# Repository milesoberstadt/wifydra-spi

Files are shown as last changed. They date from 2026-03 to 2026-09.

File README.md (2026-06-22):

# Wifydra-SPI 

A distributed WiFi beacon sniffing system using an ESP32-S3-DevKitC-1 as a central Controller and multiple ESP32-C5 nodes as Workers, with one C5 node per WiFi channel. The device uses SPI to enable synchronization of time, GPS coordinates, and aggregate WiFi discovery data.

Shout out to [lozaning's Wifydra](https://github.com/lozaning/The_Wifydra) for the inspiration!

## Features
- **Passive:** Workers operate in promiscuous mode on a fixed channel, ensuring no missed beacons due to the channel hopping in an active scan.
- **Simplified flashing:** I used SPI's CS pin assignment as unique identifiers, channels are assigned at runtime by the controller. 
- **Wigle Compatibility:** Data is stored in Wigle-compatible structures with first-seen timestamps and RSSI tracking.

## Parts List
- **Controller:** ESP32-S3-DevKitC-1, chosen for its high GPIO count and native USB/SPI support
- **Workers:** 16x Seeed Studio ESP32-C5 (or other compatible ESP32 modules)
- **GPS:** NEO-6M u-blox module, any 5v module should work
- **SD Card:** I used a Pzsmocn microSD module, any 3.3v SPI module should work
- **Buck Converter:** Bucking from 5v to 3.3v for the SD card
- **Resistors:** Every SPI connected device (including the microSD) needs a 10k ohm resistor tying the device's 3.3v line to CS

## Hardware Wiring

Current prototype diagram: https://app.cirkitdesigner.com/project/823f8a95-0d39-48f3-8a6c-8a6a2daa64cd

### SPI Bus Connections
| Signal | ESP32-S3-DevKitC-1 (Controller) | ESP32-S3 (Worker x) | SD Card (SPI Mode) |
| :--- | :--- | :--- | :--- |
| **SCLK** | GPIO 12 | GPIO 7 | SCLK |
| **MISO** | GPIO 13 | GPIO 8 | MISO |
| **MOSI** | GPIO 11 | GPIO 9 | MOSI |
| **GND** | GND | GND | GND |

### Chip Select (CS) Connections
| Target | ESP32-S3-DevKitC-1 (Controller CS Pin) | ESP32-S3 (Worker CS Pin) |
| :--- | :--- | :--- |
| **Worker 1** | GPIO 4 | GPIO 2 |
| **Worker 2** | GPIO 5 | GPIO 2 |
| **Worker 3** | GPIO 6 | GPIO 2 |
| **Worker 4** | GPIO 7 | GPIO 2 |
| **Worker 5** | GPIO 15 | GPIO 2 |
| **Worker 6** | GPIO 18 | GPIO 2 |
| **Worker 7** | GPIO 8 | GPIO 2 |
| **Worker 8** | GPIO 9 | GPIO 2 |
| **Worker 9** | GPIO 2 | GPIO 2 |
| **Worker 10** | GPIO 42 | GPIO 2 |
| **Worker 11** | GPIO 41 | GPIO 2 |
| **Worker 12** | GPIO 40 | GPIO 2 |
| **Worker 13** | GPIO 39 | GPIO 2 |
| **Worker 14** | GPIO 21 | GPIO 2 |
| **Worker 15** | GPIO 10 | GPIO 2 |
| **Worker 16** | GPIO 14 | GPIO 2 |
| **SD Card** | GPIO 1 | N/A |

### GPS Connections (Controller Only)
| Peripheral | Signal | ESP32-S3-DevKitC-1 (Controller) | Notes |
| :--- | :--- | :--- | :--- |
| **GPS (UART2)** | TX | GPIO 17 | Connect to GPS RX |
| **GPS (UART2)** | RX | GPIO 16 | Connect to GPS TX |

## Requirements
- ESP-IDF 5.x environment sourced: `. $IDF_PATH/export.sh`

## Flashing 
- **Controller:**
  ```bash
  cd controller
  idf.py build
  idf.py flash
  ```
- **Worker:**
  ```bash
  cd worker
  idf.py build
  idf.py flash
  ```

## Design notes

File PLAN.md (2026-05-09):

# SPI Communication Project Plan: ESP32 Controller to 3x ESP32-S3 Workers

### Scaling to 15 Workers (6GHz PSC channels) [TODO]
- **CS Multiplexing:** 
    - Implement a **4-to-16 Decoder** (e.g., 74HC154) or **GPIO Expander** (e.g., MCP23017) to control 15 CS lines using only 4 controller pins.
    - Software: Update SPI polling loop to set the address on the decoder pins before each transaction.
- **Bus Integrity:** 
    - Evaluate need for SPI bus buffers/drivers (e.g., 74HC244) to handle increased capacitance of 15 slaves.
    - Implement per-worker channel locking (Worker 1 -> Ch 1, Worker 2 -> Ch 2, etc.).
- **Power Management:** Investigate current draw for 15 workers + GPS + SD card

---

## Upcoming Tasks
0. [ ] Update to ESP-IDF 6
1. [ ] Prototype Phase 9 CS multiplexing hardware.
2. [ ] Evaluate SPI bus buffers for 11-worker scale.

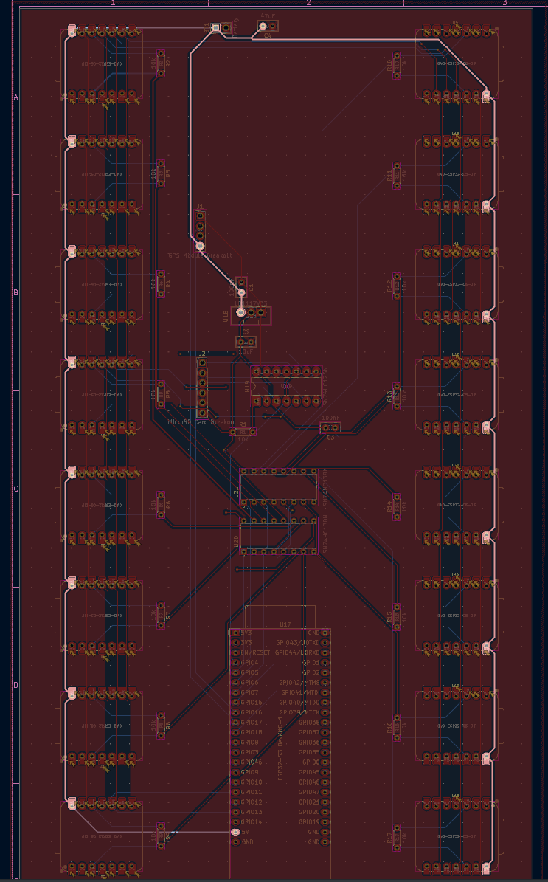
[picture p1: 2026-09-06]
img/power_net.png

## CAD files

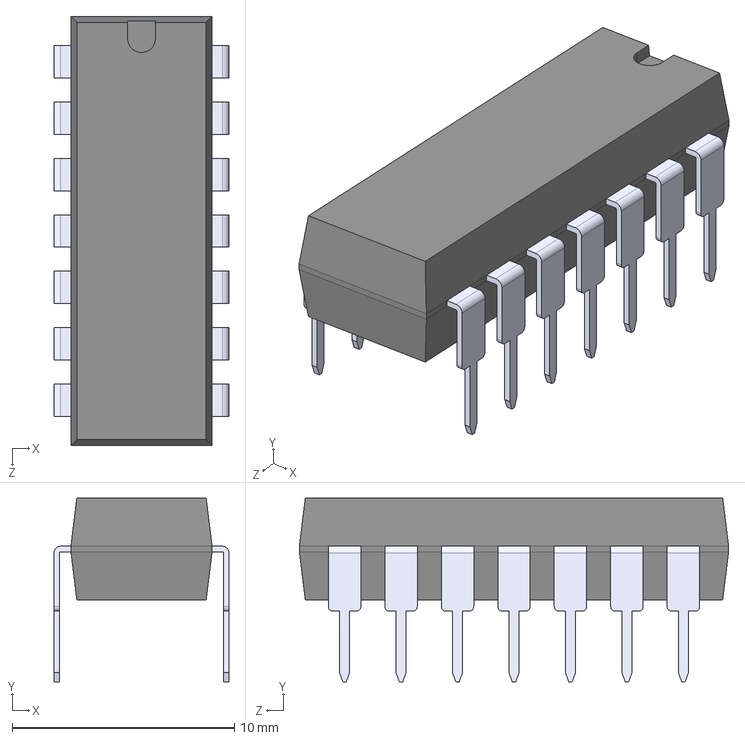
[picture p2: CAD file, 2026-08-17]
pcb/SN74HC125N/SN74HC125N.step
7.87 x 8.26 x 19.3 mm

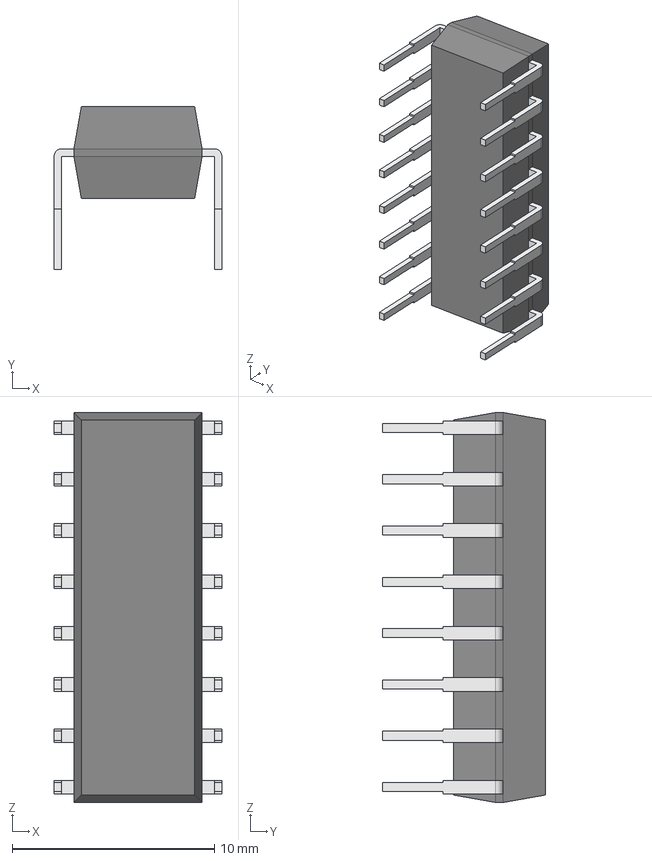
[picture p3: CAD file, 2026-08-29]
pcb/SN74HC138N/SN74HC138N.step
8.31 x 8.08 x 19.3 mm
Body001 (Mirror #1) x 9

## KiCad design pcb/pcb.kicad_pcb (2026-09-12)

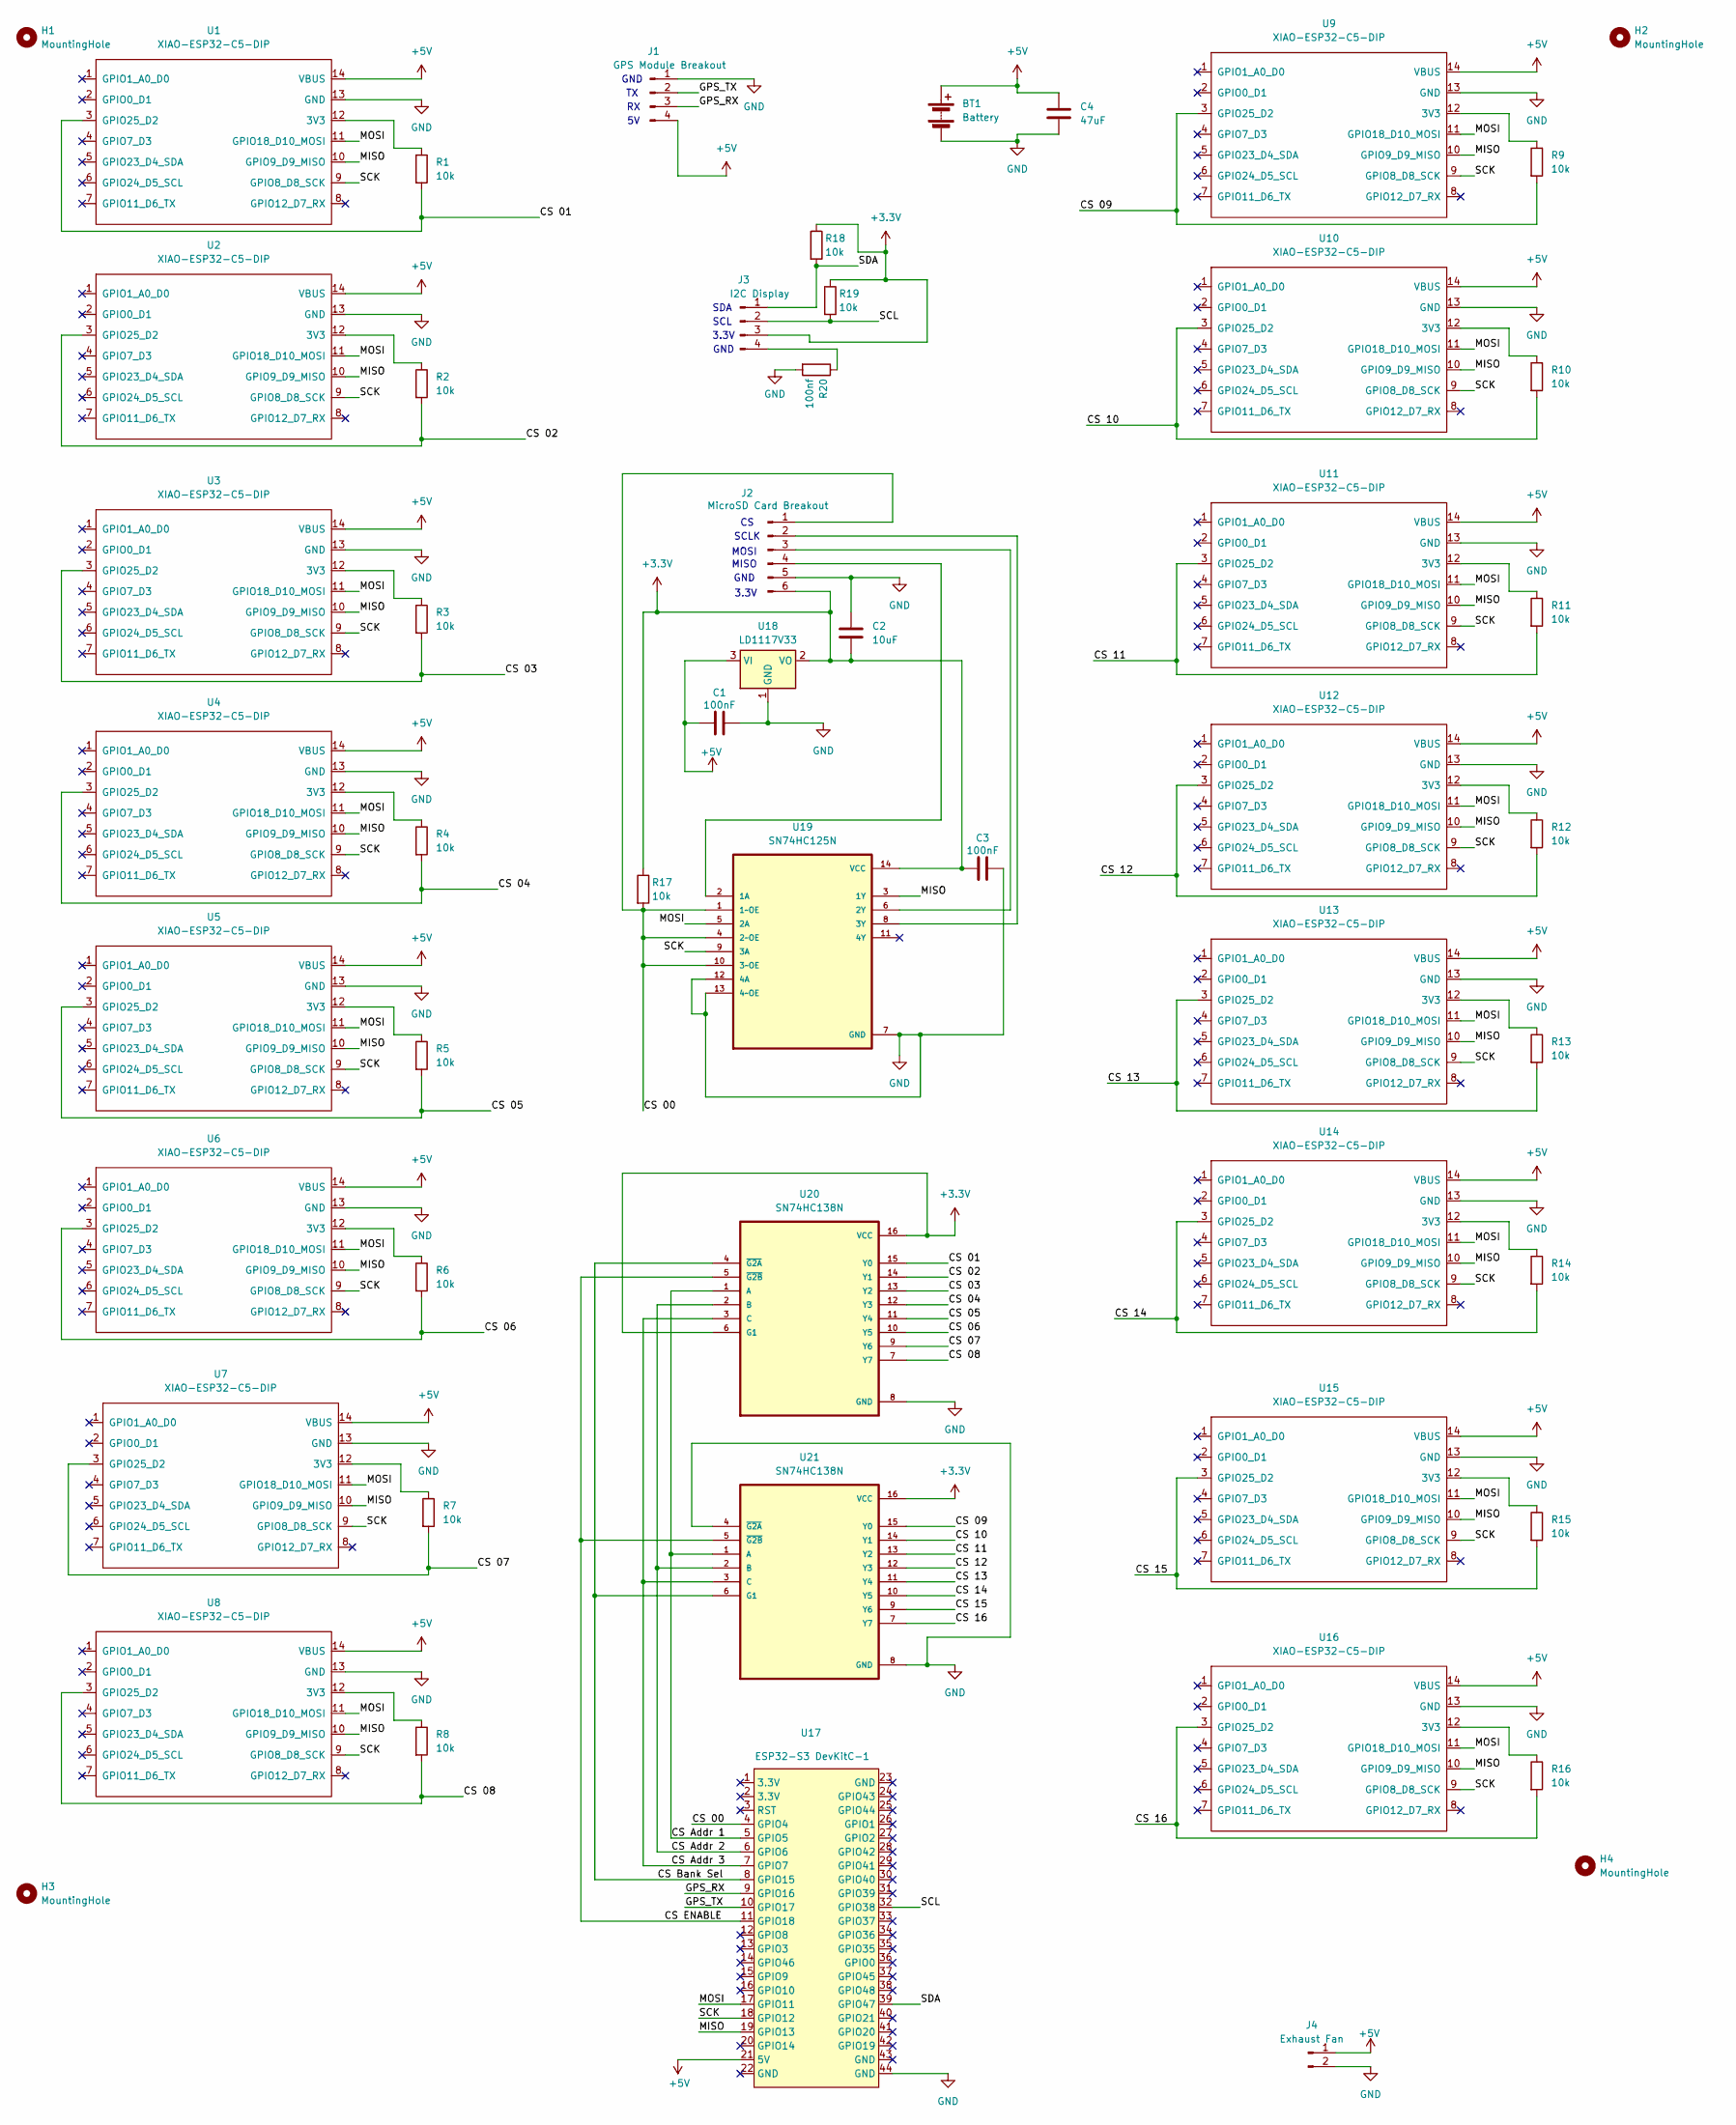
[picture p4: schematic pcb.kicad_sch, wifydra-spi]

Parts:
BT1: Battery; PinHeader_1x02_P2.54mm_Vertical
C1, C3: 100nF; C_Disc_D5.0mm_W2.5mm_P2.50mm
C2: 10uF; C_Disc_D5.0mm_W2.5mm_P2.50mm
C4: 47uF; C_Disc_D5.0mm_W2.5mm_P2.50mm
H1, H2, H3, H4: MountingHole; MountingHole_3.2mm_M3
J1: GPS Module Breakout; PinHeader_1x04_P2.54mm_Vertical
J2: MicroSD Card Breakout; PinHeader_1x06_P2.54mm_Vertical
J3: I2C Display; PinHeader_1x04_P2.54mm_Vertical
J4: Exhaust Fan; PinHeader_1x02_P2.54mm_Vertical
R1, R2, R3, R4, R5, R6, R7, R8, R9, R10, R11, R12, R13, R14, R15, R16, R17, R18, R19: 10k; R_Axial_DIN0204_L3.6mm_D1.6mm_P5.08mm_Horizontal
R20: 100nf; R_Axial_DIN0204_L3.6mm_D1.6mm_P5.08mm_Horizontal
U1, U2, U3, U4, U5, U6, U7, U8, U9, U10, U11, U12, U13, U14, U15, U16: XIAO-ESP32-C5-DIP
U17: ESP32-S3 DevKitC-1; ESP32-S3-DevKitC
U18: LD1117V33; TO-220-3_Vertical
U19: SN74HC125N; DIP-14_W7.62mm_LongPads
U20, U21: SN74HC138N; DIP794W45P254L1969H508Q16; DigiKey_Part_Number 296-1575-5-ND

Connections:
+3.3V: C2.1, C3.2, J2.6, J3.3, R17.1, R18.1, R19.1, U18.2 (VO), U19.14 (VCC), U20.6 (G1), U20.16 (VCC), U21.16 (VCC)
+5V: BT1.1 (+), C1.2, C4.2, J1.4, J4.1, U1.14 (VBUS), U2.14 (VBUS), U3.14 (VBUS), U4.14 (VBUS), U5.14 (VBUS), U6.14 (VBUS), U7.14 (VBUS), U8.14 (VBUS), U9.14 (VBUS), U10.14 (VBUS), U11.14 (VBUS), U12.14 (VBUS), U13.14 (VBUS), U14.14 (VBUS), U15.14 (VBUS), U16.14 (VBUS), U17.21 (5V), U18.3 (VI)
/CS 00: J2.1, R17.2, U17.4 (GPIO4), U19.1 (1~OE), U19.4 (2~OE), U19.10 (3~OE)
/CS 01: R1.2, U1.3 (GPIO25_D2), U20.15 (Y0)
/CS 02: R2.2, U2.3 (GPIO25_D2), U20.14 (Y1)
/CS 03: R3.2, U3.3 (GPIO25_D2), U20.13 (Y2)
/CS 04: R4.2, U4.3 (GPIO25_D2), U20.12 (Y3)
/CS 05: R5.2, U5.3 (GPIO25_D2), U20.11 (Y4)
/CS 06: R6.2, U6.3 (GPIO25_D2), U20.10 (Y5)
/CS 07: R7.2, U7.3 (GPIO25_D2), U20.9 (Y6)
/CS 08: R8.2, U8.3 (GPIO25_D2), U20.7 (Y7)
/CS 09: R9.2, U9.3 (GPIO25_D2), U21.15 (Y0)
/CS 10: R10.2, U10.3 (GPIO25_D2), U21.14 (Y1)
/CS 11: R11.2, U11.3 (GPIO25_D2), U21.13 (Y2)
/CS 12: R12.2, U12.3 (GPIO25_D2), U21.12 (Y3)
/CS 13: R13.2, U13.3 (GPIO25_D2), U21.11 (Y4)
/CS 14: R14.2, U14.3 (GPIO25_D2), U21.10 (Y5)
/CS 15: R15.2, U15.3 (GPIO25_D2), U21.9 (Y6)
/CS 16: R16.2, U16.3 (GPIO25_D2), U21.7 (Y7)
/CS Addr 1: U17.5 (GPIO5), U20.1 (A), U21.1 (A)
/CS Addr 2: U17.6 (GPIO6), U20.2 (B), U21.2 (B)
/CS Addr 3: U17.7 (GPIO7), U20.3 (C), U21.3 (C)
/CS Bank Sel: U17.8 (GPIO15), U20.4 (~G2A), U21.6 (G1)
/CS ENABLE: U17.11 (GPIO18), U20.5 (~G2B), U21.5 (~G2B)
/GPS_RX: J1.3, U17.9 (GPIO16)
/GPS_TX: J1.2, U17.10 (GPIO17)
/MISO: U1.10 (GPIO9_D9_MISO), U2.10 (GPIO9_D9_MISO), U3.10 (GPIO9_D9_MISO), U4.10 (GPIO9_D9_MISO), U5.10 (GPIO9_D9_MISO), U6.10 (GPIO9_D9_MISO), U7.10 (GPIO9_D9_MISO), U8.10 (GPIO9_D9_MISO), U9.10 (GPIO9_D9_MISO), U10.10 (GPIO9_D9_MISO), U11.10 (GPIO9_D9_MISO), U12.10 (GPIO9_D9_MISO), U13.10 (GPIO9_D9_MISO), U14.10 (GPIO9_D9_MISO), U15.10 (GPIO9_D9_MISO), U16.10 (GPIO9_D9_MISO), U17.19 (GPIO13), U19.3 (1Y)
/MOSI: U1.11 (GPIO18_D10_MOSI), U2.11 (GPIO18_D10_MOSI), U3.11 (GPIO18_D10_MOSI), U4.11 (GPIO18_D10_MOSI), U5.11 (GPIO18_D10_MOSI), U6.11 (GPIO18_D10_MOSI), U7.11 (GPIO18_D10_MOSI), U8.11 (GPIO18_D10_MOSI), U9.11 (GPIO18_D10_MOSI), U10.11 (GPIO18_D10_MOSI), U11.11 (GPIO18_D10_MOSI), U12.11 (GPIO18_D10_MOSI), U13.11 (GPIO18_D10_MOSI), U14.11 (GPIO18_D10_MOSI), U15.11 (GPIO18_D10_MOSI), U16.11 (GPIO18_D10_MOSI), U17.17 (GPIO11), U19.5 (2A)
/SCK: U1.9 (GPIO8_D8_SCK), U2.9 (GPIO8_D8_SCK), U3.9 (GPIO8_D8_SCK), U4.9 (GPIO8_D8_SCK), U5.9 (GPIO8_D8_SCK), U6.9 (GPIO8_D8_SCK), U7.9 (GPIO8_D8_SCK), U8.9 (GPIO8_D8_SCK), U9.9 (GPIO8_D8_SCK), U10.9 (GPIO8_D8_SCK), U11.9 (GPIO8_D8_SCK), U12.9 (GPIO8_D8_SCK), U13.9 (GPIO8_D8_SCK), U14.9 (GPIO8_D8_SCK), U15.9 (GPIO8_D8_SCK), U16.9 (GPIO8_D8_SCK), U17.18 (GPIO12), U19.9 (3A)
/SCL: J3.2, R19.2, U17.32 (GPIO38)
/SDA: J3.1, R18.2, U17.39 (GPIO47)
GND: BT1.2 (-), C1.1, C2.2, C3.1, C4.1, J1.1, J2.5, J4.2, R20.2, U1.13 (GND), U2.13 (GND), U3.13 (GND), U4.13 (GND), U5.13 (GND), U6.13 (GND), U7.13 (GND), U8.13 (GND), U9.13 (GND), U10.13 (GND), U11.13 (GND), U12.13 (GND), U13.13 (GND), U14.13 (GND), U15.13 (GND), U16.13 (GND), U17.44 (GND), U18.1 (GND), U19.7 (GND), U19.12 (4A), U19.13 (4~OE), U20.8 (GND), U21.4 (~G2A), U21.8 (GND)
unnamed: J2.2, U19.8 (3Y)
unnamed: J2.3, U19.6 (2Y)
unnamed: J2.4, U19.2 (1A)
unnamed: J3.4, R20.1
unnamed: R1.1, U1.12 (3V3)
unnamed: R2.1, U2.12 (3V3)
unnamed: R3.1, U3.12 (3V3)
unnamed: R4.1, U4.12 (3V3)
unnamed: R5.1, U5.12 (3V3)
unnamed: R6.1, U6.12 (3V3)
unnamed: R7.1, U7.12 (3V3)
unnamed: R8.1, U8.12 (3V3)
unnamed: R9.1, U9.12 (3V3)
unnamed: R10.1, U10.12 (3V3)
unnamed: R11.1, U11.12 (3V3)
unnamed: R12.1, U12.12 (3V3)
unnamed: R13.1, U13.12 (3V3)
unnamed: R14.1, U14.12 (3V3)
unnamed: R15.1, U15.12 (3V3)
unnamed: R16.1, U16.12 (3V3)

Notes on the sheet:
3.3V
SCL
GND
MISO
SDA
MOSI
SCLK

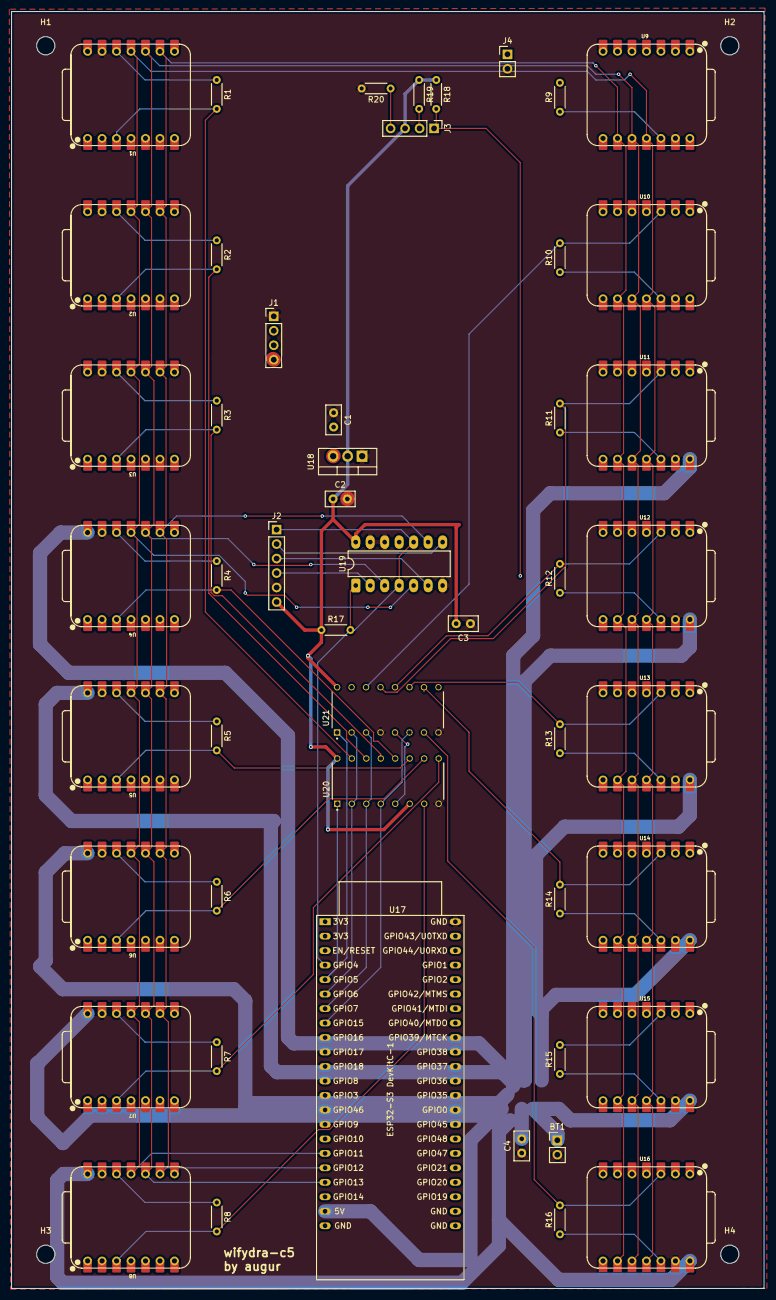
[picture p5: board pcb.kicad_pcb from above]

Board: 2 copper layers, 132.0 x 224.0 mm, 54 parts (0 on the bottom side), 52 nets.

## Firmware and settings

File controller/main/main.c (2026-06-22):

#include <stdio.h>
#include <string.h>
#include "freertos/FreeRTOS.h"
#include "freertos/task.h"
#include "driver/spi_master.h"
#include "driver/gpio.h"
#include "driver/uart.h"
#include "esp_log.h"
#include "esp_heap_caps.h"
#include "nvs_flash.h"
#include "nvs.h"
#include "esp_vfs_fat.h"
#include "driver/sdspi_host.h"
#include "driver/spi_common.h"
#include <errno.h>

static const char *TAG = "CONTROLLER";

// --- Configuration ---
#define CONFIG_WAIT_FOR_GPS_FIX true  // If true, controller won't poll workers until GPS has a fix
// ---------------------

#define GPIO_SCLK 12
#define GPIO_MISO 13
#define GPIO_MOSI 11
#define GPIO_LED  47
#define SD_CS_PIN 10
#define NUM_WORKERS 16

static const int cs_pins[NUM_WORKERS] = {
    4, 5, 6, 7, 15, 18, 8, 9, 2, 42, 41, 40, 39, 21, 10, 14
};

// GPS UART Config
#define GPS_UART_NUM UART_NUM_2
#define GPS_TX_PIN 17
#define GPS_RX_PIN 16
#define GPS_BUF_SIZE 1024

#define PAYLOAD_SIZE 5100
#define HANDSHAKE_CMD 0xAB
#define HANDSHAKE_ACK 0xBA

// NVS Keys
#define NVS_NAMESPACE "gps_data"
#define NVS_KEY_LAT "last_lat"
#define NVS_KEY_LON "last_lon"

spi_device_handle_t workers[NUM_WORKERS];

typedef struct __attribute__((packed)) {
    float latitude;
    float longitude;
} gps_coords_t;

static gps_coords_t current_gps = { .latitude = 0.0f, .longitude = 0.0f };
static uint32_t current_unix_time = 1740950400; // Default start time

uint16_t calculate_checksum(const uint8_t *data, size_t len) {
    uint32_t sum = 0;
    for (size_t i = 0; i < len; i++) sum += data[i];
    return (uint16_t)(sum & 0xFFFF);
}

typedef struct __attribute__((packed)) {
    uint8_t command;
    uint8_t wifi_channel;
    uint32_t unix_time;
    gps_coords_t gps;
    uint8_t padding[5100 - 14];
} controller_msg_t;

typedef struct __attribute__((packed)) {
    uint8_t status;
    uint8_t reserved;
    uint16_t checksum;
    uint8_t data[5100 - 4];
} worker_msg_t;

typedef struct __attribute__((packed)) {
    uint8_t bssid[6];
    char ssid[33];
    char capabilities[40];
    uint32_t first_seen;
    uint8_t channel;
    int8_t rssi;
    float lat;
    float lon;
    uint32_t hits;
    uint8_t sent;
} wigle_record_t;

static const uint8_t popular_channels[] = {1, 6, 11, 2, 7, 3, 8, 4, 9, 5, 10};
// 5 GHz non-DFS channels
// static const uint8_t popular_channels[] = {36, 40, 44, 48, 149, 153, 157, 161, 165};
// 6 GHz PSC channels
// static const uint8_t popular_channels[] = {5,21,37,53,69,85,101,117,133,149,165,181,197,213,229};
static uint8_t worker_current_channels[NUM_WORKERS]; 

// NMEA Parsing State
static bool gps_data_seen = false;
static bool gps_fix_acquired = false;
static bool sd_card_ready = false;

// SD Card Handle
sdmmc_card_t *card;
#define MOUNT_POINT "/sdcard"

void init_sd_card() {
    ESP_LOGI(TAG, "Initializing SD card (SPI)");

    esp_vfs_fat_mount_config_t mount_config = {
        .format_if_mount_failed = true,
        .max_files = 5,
        .allocation_unit_size = 16 * 1024
    };

    ESP_LOGI(TAG, "Using SPI peripheral");

    // Host configuration
    sdmmc_host_t host = SDSPI_HOST_DEFAULT();
    host.slot = HSPI_HOST; // Use the same host as workers
    host.max_freq_khz = 1000; // 1MHz stability limit

    // Device configuration
    sdspi_device_config_t dev_config = SDSPI_DEVICE_CONFIG_DEFAULT();
    dev_config.gpio_cs = SD_CS_PIN; // User specified CS pin
    dev_config.host_id = HSPI_HOST; // Explicitly set host ID

    esp_err_t ret = esp_vfs_fat_sdspi_mount(MOUNT_POINT, &host, &dev_config, &mount_config, &card);

    if (ret != ESP_OK) {
        if (ret == ESP_FAIL) {
            ESP_LOGE(TAG, "Failed to mount filesystem.");
        } else {
            ESP_LOGE(TAG, "Failed to initialize the card (%s). Check wiring and pull-ups.", esp_err_to_name(ret));
        }
        return;
    }
    ESP_LOGI(TAG, "Filesystem mounted");
    sd_card_ready = true;
}

// Simple coordinate parser (ddmm.mmmm -> decimal degrees)
float parse_coord(char *str, char dir) {
    if (!str || strlen(str) < 4) return 0.0f;
    float raw = atof(str);
    int deg = (int)(raw / 100);
    float min = raw - (deg * 100);
    float val = deg + (min / 60.0f);
    if (dir == 'S' || dir == 'W') val = -val;
    return val;
}

void save_gps_to_nvs(float lat, float lon) {
    nvs_handle_t my_handle;
    esp_err_t err = nvs_open(NVS_NAMESPACE, NVS_READWRITE, &my_handle);
    if (err != ESP_OK) return;

    nvs_set_u32(my_handle, NVS_KEY_LAT, *((uint32_t*)&lat));
    nvs_set_u32(my_handle, NVS_KEY_LON, *((uint32_t*)&lon));
    nvs_commit(my_handle);
    nvs_close(my_handle);
    ESP_LOGI(TAG, "Saved GPS to NVS: %.4f, %.4f", lat, lon);
}

void load_gps_from_nvs() {
    nvs_handle_t my_handle;
    esp_err_t err = nvs_open(NVS_NAMESPACE, NVS_READONLY, &my_handle);
    if (err != ESP_OK) {
        ESP_LOGW(TAG, "No saved GPS data found.");
        return;
    }

    uint32_t lat_int, lon_int;
    if (nvs_get_u32(my_handle, NVS_KEY_LAT, &lat_int) == ESP_OK &&
        nvs_get_u32(my_handle, NVS_KEY_LON, &lon_int) == ESP_OK) {
        
        current_gps.latitude = *((float*)&lat_int);
        current_gps.longitude = *((float*)&lon_int);
        ESP_LOGI(TAG, "Loaded GPS from NVS: %.4f, %.4f", current_gps.latitude, current_gps.longitude);
    }
    nvs_close(my_handle);
}

// UBX Checksum calculation (Fletcher-8)
void ubx_checksum(uint8_t *data, size_t len, uint8_t *ck_a, uint8_t *ck_b) {
    *ck_a = 0;
    *ck_b = 0;
    for (size_t i = 0; i < len; i++) {
        *ck_a += data[i];
        *ck_b += *ck_a;
    }
}

// Send a raw UBX message over UART
void ubx_send_message(uint8_t class, uint8_t id, uint16_t len, uint8_t *payload) {
    uint8_t header[6] = {
        0xB5, 0x62, 
        class, id, 
        (uint8_t)(len & 0xFF), (uint8_t)((len >> 8) & 0xFF)
    };
    uint8_t ck_a, ck_b;
    
    // Checksum is calculated over Class, ID, Length, and Payload
    uint8_t *chk_buf = malloc(len + 4);
    chk_buf[0] = class;
    chk_buf[1] = id;
    chk_buf[2] = header[4];
    chk_buf[3] = header[5];
    if (len > 0) memcpy(&chk_buf[4], payload, len);
    
    ubx_checksum(chk_buf, len + 4, &ck_a, &ck_b);
    free(chk_buf);

    uart_write_bytes(GPS_UART_NUM, header, 6);
    if (len > 0) uart_write_bytes(GPS_UART_NUM, payload, len);
    uint8_t footer[2] = {ck_a, ck_b};
    uart_write_bytes(GPS_UART_NUM, footer, 2);
}

// Assist GPS module with last known position (UBX-AID-INI)
void ubx_assist_cold_start(float lat, float lon) {
    if (lat == 0.0f && lon == 0.0f) return;

    ESP_LOGI(TAG, "Sending UBX assistance: %.4f, %.4f", lat, lon);

    typedef struct __attribute__((packed)) {
        int32_t ecefX_or_lat;
        int32_t ecefY_or_lon;
        int32_t ecefZ_or_alt;
        uint32_t posAcc;
        uint16_t tmCfg;
        uint16_t wn;
        uint32_t tow;
        int32_t towNs;
        int32_t tAcc;
        int32_t fAcc;
        int32_t clkD;
        uint32_t clkDAcc;
        uint32_t flags;
    } ubx_aid_ini_t;

    ubx_aid_ini_t msg = {0};
    msg.ecefX_or_lat = (int32_t)(lat * 1e7);
    msg.ecefY_or_lon = (int32_t)(lon * 1e7);
    msg.posAcc = 100000; // 1km accuracy for assistance
    msg.flags = 0x01 | 0x20; // 0x01 = pos valid, 0x20 = alt invalid (use 2D)

    ubx_send_message(0x0B, 0x01, sizeof(msg), (uint8_t *)&msg);
}

// Logging State
static char current_log_filename[64] = "";
static bool log_file_created = false;
#define LOG_BUFFER_SIZE 4096
static char *log_buffer = NULL;
static size_t log_buffer_len = 0;

const char* WIGLE_HEADER = "WigleWifi-1.0,appRelease=1.0,model=ESP32-Scanner,release=1.0,device=ESP32-Scanner,display=ESP32-Scanner,board=ESP32,brand=Espressif\n"
                           "MAC,SSID,AuthMode,FirstSeen,Channel,RSSI,CurrentLatitude,CurrentLongitude,AltitudeMeters,AccuracyMeters,Type\n";

void flush_log_buffer() {
    if (!sd_card_ready || !log_file_created || log_buffer_len == 0) return;

    FILE *f = fopen(current_log_filename, "a");
    if (f == NULL) {
        ESP_LOGE(TAG, "Failed to open log file for flushing! (errno: %d)", errno);
        return;
    }
    
    size_t written = fwrite(log_buffer, 1, log_buffer_len, f);
    if (written != log_buffer_len) {
        ESP_LOGE(TAG, "Failed to write all data to SD card!");
    }
    
    fclose(f);
    log_buffer_len = 0;
}

void create_wigle_log(const char* date, const char* time) {
    if (!sd_card_ready || log_file_created || !date || !time) return;

    // Allocate buffer on first use
    if (log_buffer == NULL) {
        log_buffer = malloc(LOG_BUFFER_SIZE);
    }

    // Sanitize time: GPS often gives "HHMMSS.SS", we only want "HHMMSS"
    char clean_time[7];
    strncpy(clean_time, time, 6);
    clean_time[6] = '\0';

    // Reformat date from DDMMYY to YYYYMMDD
    char formatted_date[9];
    if (strlen(date) == 6) {
        // GPS date is DDMMYY
        formatted_date[0] = '2'; // Assume 20xx
        formatted_date[1] = '0';
        formatted_date[2] = date[4]; // Y
        formatted_date[3] = date[5]; // Y
        formatted_date[4] = date[2]; // M
        formatted_date[5] = date[3]; // M
        formatted_date[6] = date[0]; // D
        formatted_date[7] = date[1]; // D
        formatted_date[8] = '\0';
    } else {
        strncpy(formatted_date, date, 8);
        formatted_date[8] = '\0';
    }

    // Use the descriptive filename: YYYYMMDD_HHMMSS.csv
    snprintf(current_log_filename, sizeof(current_log_filename), "%s/%s_%s.csv", MOUNT_POINT, formatted_date, clean_time);
    ESP_LOGI(TAG, "Creating new log file: %s", current_log_filename);

    FILE *f = fopen(current_log_filename, "w");
    if (f == NULL) {
        ESP_LOGE(TAG, "Failed to create log file! (errno: %d, %s)", errno, strerror(errno));
        return;
    }
    fprintf(f, "%s", WIGLE_HEADER);
    fclose(f);
    log_file_created = true;
}

void append_to_wigle_log(const wigle_record_t *rec) {
    if (!sd_card_ready || !log_file_created || log_buffer == NULL) return;

    char line[200];
    int len = snprintf(line, sizeof(line), "%02X:%02X:%02X:%02X:%02X:%02X,%s,[WPA2-PSK-CCMP][ESS],2026-03-28 00:00:00,%d,%d,%.6f,%.6f,0,0,WIFI\n",
            rec->bssid[0], rec->bssid[1], rec->bssid[2],
            rec->bssid[3], rec->bssid[4], rec->bssid[5],
            rec->ssid, rec->channel, rec->rssi,
            rec->lat, rec->lon);

    if (log_buffer_len + len >= LOG_BUFFER_SIZE) {
        flush_log_buffer();
    }

    if (len > 0 && len < sizeof(line)) {
        memcpy(log_buffer + log_buffer_len, line, len);
        log_buffer_len += len;
    }
}

// $GPRMC,123519,A,4807.038,N,01131.000,E,022.4,084.4,230394,003.1,W*6A
void parse_nmea_rmc(char *line) {
    if (!gps_data_seen) {
        ESP_LOGI(TAG, "GPS Data stream detected.");
        gps_data_seen = true;
    }

    if (strncmp(line, "$GPRMC", 6) == 0 || strncmp(line, "$GNRMC", 6) == 0) {
        char *token;
        char *rest = line;
        int field = 0;
        char *time = NULL, *status = NULL, *lat = NULL, *ns = NULL, *lon = NULL, *ew = NULL, *date = NULL;

        while ((token = strsep(&rest, ",")) != NULL) {
            switch (field) {
                case 1: time = token; break;
                case 2: status = token; break;
                case 3: lat = token; break;
                case 4: ns = token; break;
                case 5: lon = token; break;
                case 6: ew = token; break;
                case 9: date = token; break;
            }
            field++;
        }

        // Create log file as soon as we have a date/time (even without fix)
        if (date && time && strlen(date) == 6 && strlen(time) >= 6) {
            create_wigle_log(date, time);
        }

        if (status && strcmp(status, "A") == 0) {
            float new_lat = parse_coord(lat, ns ? ns[0] : 'N');
            float new_lon = parse_coord(lon, ew ? ew[0] : 'E');

            if (!gps_fix_acquired) {
                ESP_LOGI(TAG, "GPS Fix Acquired! Lat: %.4f, Lon: %.4f", new_lat, new_lon);
                gps_fix_acquired = true;
                save_gps_to_nvs(new_lat, new_lon);
            }
            
            current_gps.latitude = new_lat;
            current_gps.longitude = new_lon;
        }
    }
}

void gps_task(void *pvParameters) {
    uint8_t *data = (uint8_t *)malloc(GPS_BUF_SIZE);
    while (1) {
        int len = uart_read_bytes(GPS_UART_NUM, data, GPS_BUF_SIZE - 1, pdMS_TO_TICKS(500));
        if (len > 0) {
            data[len] = '\0';
            parse_nmea_rmc((char *)data);
        }
    }
}

void status_led_task(void *pvParameters) {
    gpio_reset_pin(GPIO_LED);
    gpio_set_direction(GPIO_LED, GPIO_MODE_OUTPUT);
    
    while (1) {
        if (gps_fix_acquired) {
            gpio_set_level(GPIO_LED, 1);
            vTaskDelay(pdMS_TO_TICKS(500));
        } else if (gps_data_seen) {
            gpio_set_level(GPIO_LED, 1);
            vTaskDelay(pdMS_TO_TICKS(200));
            gpio_set_level(GPIO_LED, 0);
            vTaskDelay(pdMS_TO_TICKS(200));
        } else {
            gpio_set_level(GPIO_LED, 0);
            vTaskDelay(pdMS_TO_TICKS(500));
        }
    }
}

void app_main(void) {
    ESP_LOGI(TAG, "Controller starting...");

    // Initialize all CS pins to HIGH early to prevent bus interference
    uint64_t pin_mask = (1ULL << SD_CS_PIN);
    for (int i = 0; i < NUM_WORKERS; i++) {
        pin_mask |= (1ULL << cs_pins[i]);
    }
    gpio_config_t cs_cfg = {
        .pin_bit_mask = pin_mask,
        .mode = GPIO_MODE_OUTPUT,
        .pull_up_en = GPIO_PULLUP_ENABLE,
        .pull_down_en = GPIO_PULLDOWN_DISABLE,
        .intr_type = GPIO_INTR_DISABLE
    };
    gpio_config(&cs_cfg);
    for (int i = 0; i < NUM_WORKERS; i++) {
        gpio_set_level(cs_pins[i], 1);
    }
    gpio_set_level(SD_CS_PIN, 1);
    
    // Start Status LED Task
    xTaskCreate(status_led_task, "status_led_task", 2048, NULL, 5, NULL);

    // Initialize NVS
    esp_err_t ret = nvs_flash_init();
    if (ret == ESP_ERR_NVS_NO_FREE_PAGES || ret == ESP_ERR_NVS_NEW_VERSION_FOUND) {
        ESP_ERROR_CHECK(nvs_flash_erase());
        ret = nvs_flash_init();
    }
    ESP_ERROR_CHECK(ret);

    // Load last known position for warm start
    load_gps_from_nvs();

    // Configure UART for GPS early to send assistance
    uart_config_t uart_config = {
        .baud_rate = 9600,
        .data_bits = UART_DATA_8_BITS,
        .parity = UART_PARITY_DISABLE,
        .stop_bits = UART_STOP_BITS_1,
        .flow_ctrl = UART_HW_FLOWCTRL_DISABLE,
        .source_clk = UART_SCLK_DEFAULT,
    };
    ESP_ERROR_CHECK(uart_driver_install(GPS_UART_NUM, GPS_BUF_SIZE * 2, 0, 0, NULL, 0));
    ESP_ERROR_CHECK(uart_param_config(GPS_UART_NUM, &uart_config));
    ESP_ERROR_CHECK(uart_set_pin(GPS_UART_NUM, GPS_TX_PIN, GPS_RX_PIN, UART_PIN_NO_CHANGE, UART_PIN_NO_CHANGE));

    // Send assistance data to GPS module
    ubx_assist_cold_start(current_gps.latitude, current_gps.longitude);

    spi_bus_config_t buscfg = {
        .miso_io_num = GPIO_MISO, .mosi_io_num = GPIO_MOSI, .sclk_io_num = GPIO_SCLK,
        .max_transfer_sz = PAYLOAD_SIZE + 100
    };
    ESP_ERROR_CHECK(spi_bus_initialize(HSPI_HOST, &buscfg, SPI_DMA_CH_AUTO));

    // Enable internal pull-ups for the SPI bus
    gpio_set_pull_mode(GPIO_MISO, GPIO_PULLUP_ONLY);
    gpio_set_pull_mode(GPIO_MOSI, GPIO_PULLUP_ONLY);
    gpio_set_pull_mode(GPIO_SCLK, GPIO_PULLUP_ONLY);

    // Initialize SD Card IMMEDIATELY after SPI bus is ready (must be first communication)
    init_sd_card();

    vTaskDelay(pdMS_TO_TICKS(1000));
    for (int i = 0; i < NUM_WORKERS; i++) {
        worker_current_channels[i] = popular_channels[i % (sizeof(popular_channels) / sizeof(popular_channels[0]))];
    }

    // Start GPS Task (after SD card is initialized so it can create logs)
    xTaskCreate(gps_task, "gps_task", 4096, NULL, 5, NULL);

    for (int i = 0; i < NUM_WORKERS; i++) {
        spi_device_interface_config_t devcfg = {
            .clock_speed_hz = 1 * 1000 * 1000, 
            .mode = 0,
            .spics_io_num = cs_pins[i],
            .queue_size = 7,
            .cs_ena_pretrans = 2,
        };
        ESP_ERROR_CHECK(spi_bus_add_device(HSPI_HOST, &devcfg, &workers[i]));
    }

    controller_msg_t *tx = heap_caps_calloc(1, sizeof(controller_msg_t), MALLOC_CAP_DMA);
    worker_msg_t *rx = heap_caps_calloc(1, sizeof(worker_msg_t), MALLOC_CAP_DMA);

    if (CONFIG_WAIT_FOR_GPS_FIX) {
        ESP_LOGI(TAG, "Waiting for valid GPS fix before polling workers...");
        while (!gps_fix_acquired) {
            vTaskDelay(pdMS_TO_TICKS(1000));
        }
        ESP_LOGI(TAG, "GPS Fix acquired! Starting Worker Polling...");
    } else {
        ESP_LOGI(TAG, "Starting Worker Polling (Using last-known NVS GPS if available)...");
    }

    while (1) {
        for (int i = 0; i < NUM_WORKERS; i++) {
            ESP_LOGI(TAG, "Polling Worker %d...", i + 1);
            memset(tx, 0, sizeof(controller_msg_t));
            tx->command = HANDSHAKE_CMD;
            tx->wifi_channel = worker_current_channels[i];
            tx->unix_time = current_unix_time; // Send live GPS time
            tx->gps = current_gps;             // Send live coordinates

            spi_transaction_t t = { .length = PAYLOAD_SIZE * 8, .tx_buffer = tx, .rx_buffer = rx };
            if (spi_device_transmit(workers[i], &t) == ESP_OK) {
                if (rx->status == HANDSHAKE_ACK) {
                    uint16_t cal = calculate_checksum(rx->data, sizeof(rx->data));
                    if (rx->checksum == cal) {
                        int count = rx->reserved;
                        ESP_LOGI(TAG, "Worker %d OK. APs: %d", i+1, count);
                        wigle_record_t *rec = (wigle_record_t *)rx->data;
                        for (int j = 0; j < count; j++) {
                            if (j < 2) {
                                ESP_LOGI(TAG, "  AP: %s (%02X:%02X:%02X:%02X:%02X:%02X) RSSI:%d Hits:%lu", 
                                         rec[j].ssid, rec[j].bssid[0], rec[j].bssid[1], rec[j].bssid[2],
                                         rec[j].bssid[3], rec[j].bssid[4], rec[j].bssid[5], rec[j].rssi, (unsigned long)rec[j].hits);
                            }
                            append_to_wigle_log(&rec[j]);
                        }
                        flush_log_buffer();
                    } else ESP_LOGE(TAG, "Worker %d Checksum Fail!", i+1);
                } else ESP_LOGW(TAG, "Worker %d Handshake Fail (0x%02X)", i+1, rx->status);
            }
            vTaskDelay(pdMS_TO_TICKS(1000));
        }
        
        // If GPS isn't fixing, manually increment time for testing
        if (current_gps.latitude == 0.0f) {
            current_unix_time += 15;
        }
        
        vTaskDelay(pdMS_TO_TICKS(5000));
    }
}

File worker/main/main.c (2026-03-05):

#include <stdio.h>
#include <string.h>
#include "freertos/FreeRTOS.h"
#include "freertos/task.h"
#include "freertos/semphr.h"
#include "driver/spi_slave.h"
#include "driver/gpio.h"
#include "esp_log.h"
#include "esp_heap_caps.h"
#include "esp_rom_sys.h"
#include "esp_wifi.h"
#include "nvs_flash.h"

static const char *TAG = "WORKER";

#define GPIO_SCLK 7
#define GPIO_MISO 8
#define GPIO_MOSI 9
#define GPIO_CS   2

#define PAYLOAD_SIZE 5100
#define HANDSHAKE_ACK 0xBA

typedef struct __attribute__((packed)) {
    float latitude;
    float longitude;
} gps_coords_t;

typedef struct __attribute__((packed)) {
    uint8_t command;
    uint8_t wifi_channel;
    uint32_t unix_time;
    gps_coords_t gps;
    uint8_t padding[5100 - 14];
} controller_msg_t;

typedef struct __attribute__((packed)) {
    uint8_t status;
    uint8_t reserved; // Number of records in this packet
    uint16_t checksum;
    uint8_t data[5100 - 4];
} worker_msg_t;

typedef struct __attribute__((packed)) {
    uint8_t bssid[6];
    char ssid[33];
    char capabilities[40];
    uint32_t first_seen;
    uint8_t channel;
    int8_t rssi;
    float lat;
    float lon;
    uint32_t hits;
    uint8_t sent; // 0 = unsent, 1 = sent
} wigle_record_t;

#define MAX_MACS 500
#define RECORDS_PER_BUFFER 50 // How many fit in 5096 bytes (98 bytes each)

static wigle_record_t *mac_table = NULL;
static int mac_count = 0;
static uint8_t current_wifi_ch = 0;
static uint32_t current_unix_time = 0;
static gps_coords_t current_gps = {0};
static SemaphoreHandle_t mac_mutex = NULL;

// Indices of records currently being sent
static int in_flight_indices[RECORDS_PER_BUFFER];
static int in_flight_count = 0;

uint16_t calculate_checksum(const uint8_t *data, size_t len) {
    uint32_t sum = 0;
    for (size_t i = 0; i < len; i++) sum += data[i];
    return (uint16_t)(sum & 0xFFFF);
}

void parse_beacon_ie(const uint8_t *payload, size_t len, char *ssid, char *cap) {
    size_t offset = 36;
    strcpy(ssid, "<hidden>");
    strcpy(cap, "[ESS]");
    while (offset + 2 <= len) {
        uint8_t tag_id = payload[offset];
        uint8_t tag_len = payload[offset + 1];
        if (offset + 2 + tag_len > len) break;
        if (tag_id == 0 && tag_len > 0) {
            int slen = tag_len > 32 ? 32 : tag_len;
            memcpy(ssid, &payload[offset + 2], slen);
            ssid[slen] = '\0';
        } else if (tag_id == 48) strcpy(cap, "[WPA2-PSK-CCMP][ESS]");
        offset += 2 + tag_len;
    }
}

void wifi_sniffer_packet_handler(void* buf, wifi_promiscuous_pkt_type_t type) {
    if (type != WIFI_PKT_MGMT || current_wifi_ch == 0 || mac_table == NULL || mac_mutex == NULL) return;
    wifi_promiscuous_pkt_t *pkt = (wifi_promiscuous_pkt_t *)buf;
    if (pkt->rx_ctrl.sig_len < 36 || pkt->payload[0] != 0x80) return;

    if (xSemaphoreTake(mac_mutex, 0) == pdTRUE) {
        uint8_t *bssid = &pkt->payload[10];
        bool found = false;
        for (int i = 0; i < mac_count; i++) {
            if (memcmp(mac_table[i].bssid, bssid, 6) == 0) {
                mac_table[i].hits++;
                mac_table[i].rssi = pkt->rx_ctrl.rssi;
                found = true;
                break;
            }
        }
        if (!found) {
            if (mac_count < MAX_MACS) {
                // Table not full, add to end
                wigle_record_t *r = &mac_table[mac_count];
                memcpy(r->bssid, bssid, 6);
                r->hits = 1;
                r->first_seen = current_unix_time;
                r->channel = current_wifi_ch;
                r->rssi = pkt->rx_ctrl.rssi;
                r->lat = current_gps.latitude;
                r->lon = current_gps.longitude;
                r->sent = 0;
                parse_beacon_ie(pkt->payload, pkt->rx_ctrl.sig_len, r->ssid, r->capabilities);
                mac_count++;
                ESP_LOGI(TAG, "New AP [%d]: %s", mac_count, r->ssid);
            } else {
                // Table FULL. Look for a record that was already sent to overwrite.
                for (int i = 0; i < MAX_MACS; i++) {
                    if (mac_table[i].sent == 1) {
                        wigle_record_t *r = &mac_table[i];
                        memcpy(r->bssid, bssid, 6);
                        r->hits = 1;
                        r->first_seen = current_unix_time;
                        r->channel = current_wifi_ch;
                        r->rssi = pkt->rx_ctrl.rssi;
                        r->lat = current_gps.latitude;
                        r->lon = current_gps.longitude;
                        r->sent = 0; // Mark as unsent again
                        parse_beacon_ie(pkt->payload, pkt->rx_ctrl.sig_len, r->ssid, r->capabilities);
                        ESP_LOGI(TAG, "Table full, overwriting sent record with: %s", r->ssid);
                        break;
                    }
                }
            }
        }
        xSemaphoreGive(mac_mutex);
    }
}

void wifi_init_sniffer(void) {
    esp_err_t ret = nvs_flash_init();
    if (ret == ESP_ERR_NVS_NO_FREE_PAGES || ret == ESP_ERR_NVS_NEW_VERSION_FOUND) {
        ESP_ERROR_CHECK(nvs_flash_erase());
        ret = nvs_flash_init();
    }
    ESP_ERROR_CHECK(ret);
    ESP_ERROR_CHECK(esp_netif_init());
    ESP_ERROR_CHECK(esp_event_loop_create_default());
    wifi_init_config_t cfg = WIFI_INIT_CONFIG_DEFAULT();
    ESP_ERROR_CHECK(esp_wifi_init(&cfg));
    ESP_ERROR_CHECK(esp_wifi_set_storage(WIFI_STORAGE_RAM));
    ESP_ERROR_CHECK(esp_wifi_set_mode(WIFI_MODE_NULL));
    ESP_ERROR_CHECK(esp_wifi_start());
    ESP_ERROR_CHECK(esp_wifi_set_promiscuous_rx_cb(&wifi_sniffer_packet_handler));
}
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

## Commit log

2026-03-04 change message struct to assign a wifi channel and send current GPS
2026-03-04 track sent status of records
2026-03-08 Fix a bug and add blink for GPS lock status
    [main.c]
2026-03-08 use ubx commands to seed gps for faster first fix
    [main.c]
2026-03-08 wait to scan until we have gps fix
    [main.c]
2026-03-28 Replace sdmmc interface with sd spi module, we're writing headers correctly!
    [main.c]
2026-03-28 Writing APs to SD card correctly!!!
    [main.c]
2026-05-09 init a kicad 10 project
    [pcb.kicad_pcb, pcb.kicad_sch]
2026-05-09 Start the schematic for the PCB
    [pcb.kicad_sch]
2026-06-20 More wiring on the PCB design
    [pcb.kicad_pcb, pcb.kicad_sch]
2026-06-21 tidy schematic
    [pcb.kicad_sch]
2026-06-22 Increase worker count to 16, wire up the PCB
    [pcb.kicad_sch]
2026-06-22 tidy up warnings
    [pcb.kicad_pcb, pcb.kicad_sch]
2026-06-22 more progress with the PCB layout
    [pcb.kicad_pcb, pcb.kicad_sch]
2026-06-22 swap voltage regulator for an LD1117v33 regulator
    [pcb.kicad_pcb, pcb.kicad_sch]
2026-06-22 more tweaks before routing
    [pcb.kicad_pcb]
2026-08-05 add capacitors to i/o of LD1117
    [pcb.kicad_pcb, pcb.kicad_sch]
2026-08-05 add CS labels
    [pcb.kicad_sch]
2026-08-17 Added net classes and colors, squared away controller footprint, sorted power input battery symbol
    [pcb.kicad_pcb, pcb.kicad_sch]
2026-08-17 Add my 74HC125 for protecting the SPI lines from microsd card bus hogging
    [SN74HC125N.step, pcb.kicad_sch]
2026-08-22 Add 74HC125 for SPI bus protection from microsd modules
    [pcb.kicad_sch]
2026-08-29 Fix ERC warnings, place new components in PCB
    [SN74HC138N.step, pcb.kicad_pcb, pcb.kicad_sch]
2026-08-29 tidy up
    [pcb.kicad_pcb]
2026-08-29 relative symbol libs, fix erc again
    [pcb.kicad_sch]
2026-08-30 implement more feedback from red :D
    [pcb.kicad_pcb, pcb.kicad_sch]
2026-08-31 Reroute the board!
    [pcb.kicad_pcb]
2026-08-31 Add brownout protection
    [pcb.kicad_pcb, pcb.kicad_sch]
2026-09-06 0.3mm power net
    [pcb.kicad_pcb]
2026-09-07 Thicker tracks, remove redundant ground lines, mounting holes
    [pcb.kicad_pcb, pcb.kicad_sch]
2026-09-07 Fix 15/16 ordering
    [pcb.kicad_pcb, pcb.kicad_sch]
2026-09-12 add exhaust fan power
    [pcb.kicad_pcb, pcb.kicad_sch]
2026-09-12 experimenting with star power
    [pcb.kicad_pcb]
